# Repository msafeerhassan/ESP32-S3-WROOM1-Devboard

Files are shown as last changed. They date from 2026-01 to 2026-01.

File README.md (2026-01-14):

# ESP32-S3-WROOM1-Devboard
A Custom ESP32-S3-WROOM1 N16R8 Development Board completely designed by me.

This project features raw ESP32-S3-WROOM1 N16R8 Chip to convert it into a professional development board. Several resistors are used along with capacitors for perfect circuit current flowing. 3 RGB colored LEDS are also placed on the PCB alongwith two Switch Push Buttons. A cool logo is placed on bottom right while text with each Pin is mentioned for ease of use in real life.

## Schematic Diagram:



## PCB:





### Made by Safeer Hassan

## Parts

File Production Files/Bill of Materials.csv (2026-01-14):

Component | Quantity
10uF 50V Capacitors | 3
22uF 50V Capacitors | 2
100nF Capacitors | 3
LD1117S33TR SOT223 | 1
S3-WROOM-1-N16R8 | 1
5.1K Ohms Resistors | 5
PinHeader_1x20_P2.00mm_Vertical | 2
USB-C Receptacle_HCTL_HC-TYPE-C-16P-01A | 1
RED LED | 1
BLUE LED | 1
GREEN LED | 1
SW_PUSH Button | 2
Note: (PCBA to be ordered, so no product prices/links)

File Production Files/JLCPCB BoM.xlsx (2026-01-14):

Comment | Designator | Footprint
10uf | C1,C3 | 1206
22uf | C4 | 1206
100nf | C2,C5 | 603
RED | D1 | 805
GREEN | D2 | 805
BLUE | D3 | 805
USB_C_Receptacle_USB2.0_16P | J1 | USB_C_Receptacle_HCTL_HC-TYPE-C-16P-01A
Conn_01x20_Pin | J2,J3 | PinHeader_1x20_P2.00mm_Vertical
5.1k | R1,R2,R3,R4,R5 | 603
SW_Push | SW1,SW2 | SW_SPST_B3S-1000
ESP32-S3-WROOM-1 | U1 | ESP32-S3-WROOM-1
LD1117S33TR_SOT223 | U2 | SOT-223-3_TabPin2

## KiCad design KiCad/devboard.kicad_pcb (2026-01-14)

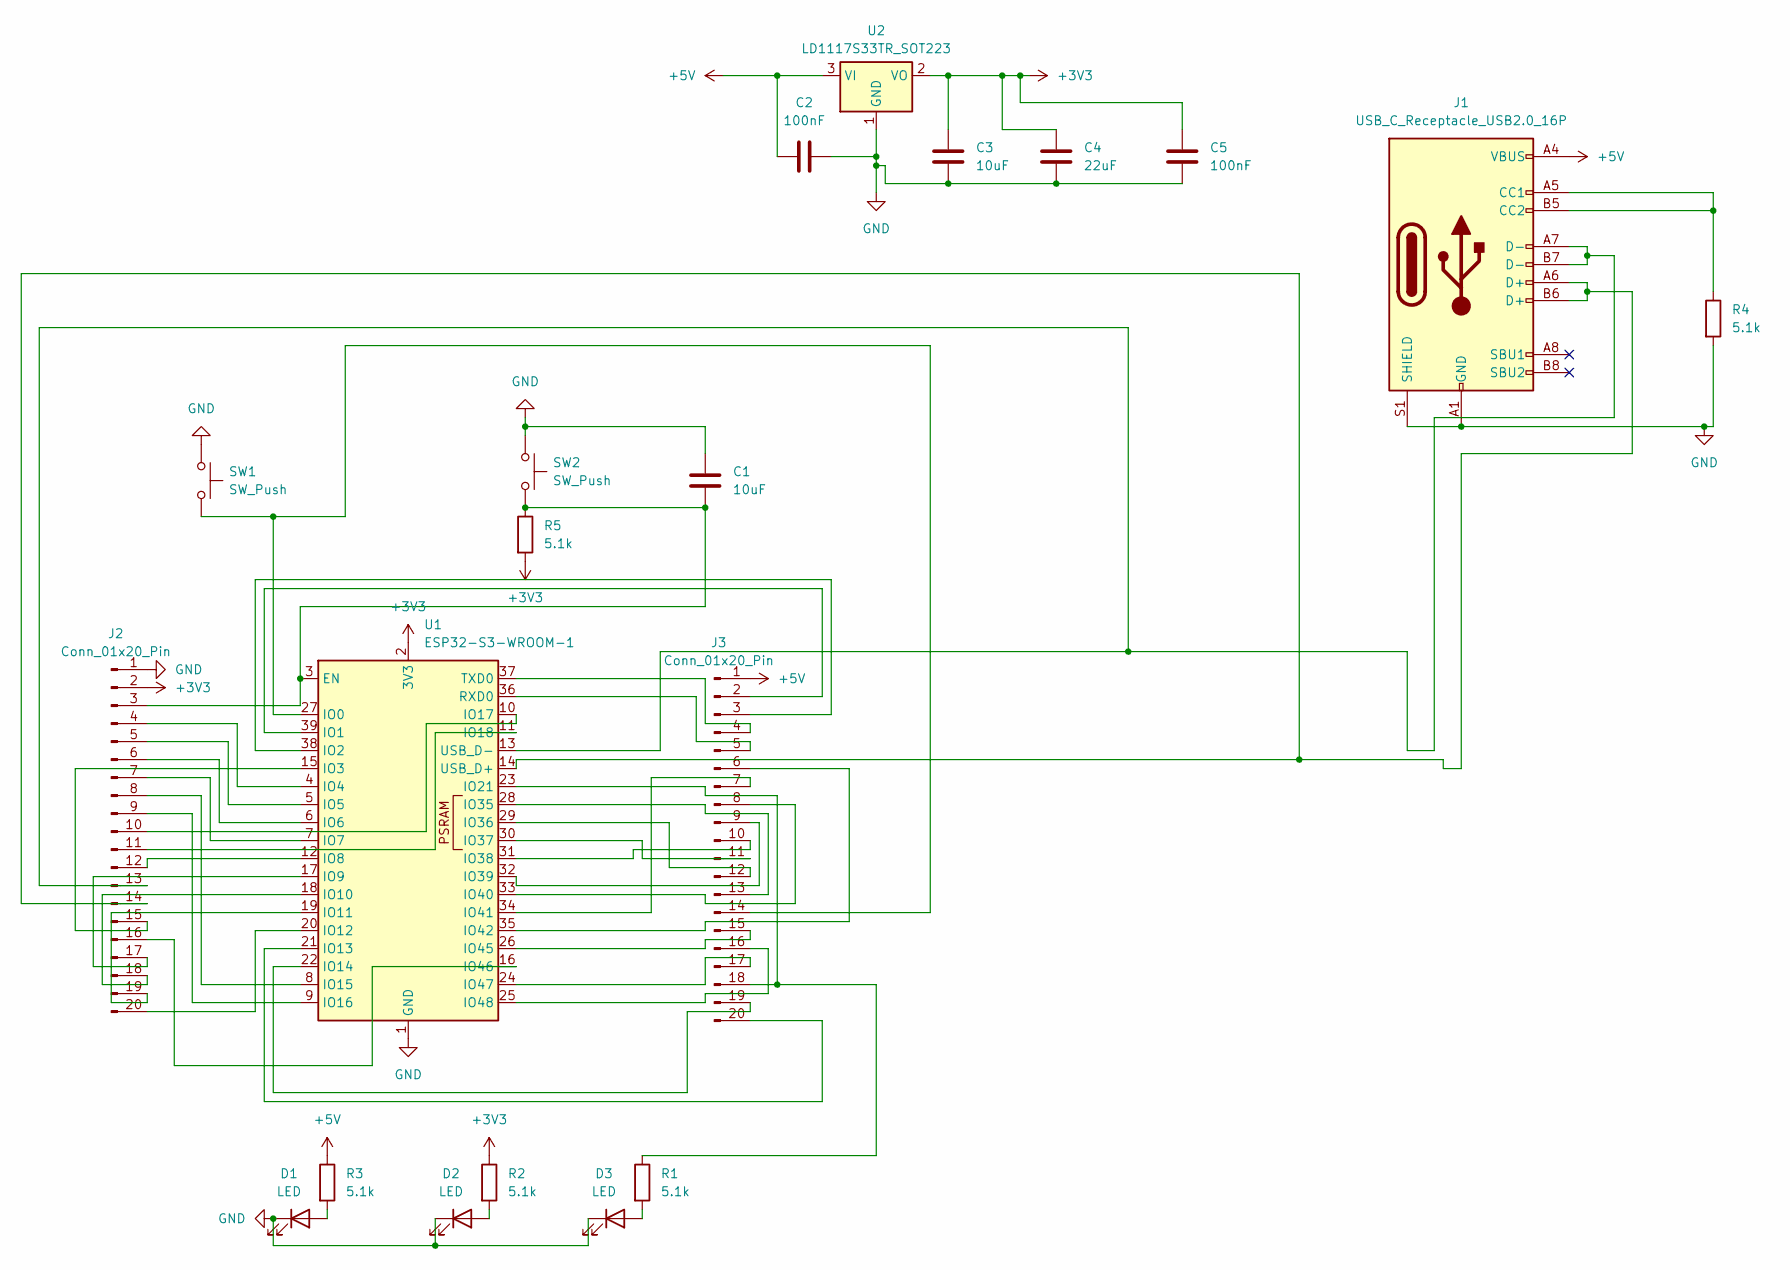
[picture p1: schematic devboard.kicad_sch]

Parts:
C1, C3: 10uF; C_1206_3216Metric_Pad1.33x1.80mm_HandSolder
C2, C5: 100nF; C_0603_1608Metric_Pad1.08x0.95mm_HandSolder
C4: 22uF; C_1206_3216Metric_Pad1.33x1.80mm_HandSolder
D1, D2, D3: LED; LED_0805_2012Metric_Pad1.15x1.40mm_HandSolder
J1: USB_C_Receptacle_USB2.0_16P; USB_C_Receptacle_HCTL_HC-TYPE-C-16P-01A
J2, J3: Conn_01x20_Pin; PinHeader_1x20_P2.00mm_Vertical
R1, R2, R3, R4, R5: 5.1k; R_0603_1608Metric_Pad0.98x0.95mm_HandSolder
SW1, SW2: SW_Push; SW_SPST_B3S-1000
U1: ESP32-S3-WROOM-1
U2: LD1117S33TR_SOT223; SOT-223-3_TabPin2

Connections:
+3V3: C3.1, C4.1, C5.1, J2.2, R2.1, R5.2, U1.2 (3V3), U2.2 (VO)
+5V: C2.1, J1.A4 (VBUS), J1.A9 (VBUS), J1.B4 (VBUS), J1.B9 (VBUS), J3.1, R3.1, U2.3 (VI)
GND: C1.1, C2.2, C3.2, C4.2, C5.2, D1.1 (K), D2.1 (K), D3.1 (K), J1.A1 (GND), J1.A12 (GND), J1.B1 (GND), J1.B12 (GND), J1.S1 (SHIELD), J2.1, R4.2, SW1.1, SW2.1, U1.1 (GND), U1.40 (GND), U1.41 (GND), U2.1 (GND)
unnamed: D1.2 (A), R3.2
unnamed: D2.2 (A), R2.2
unnamed: D3.2 (A), R1.2
unnamed: J1.A5 (CC1), J1.B5 (CC2), R4.1
unnamed: C1.2, J2.3, R5.1, SW2.2, U1.3 (EN)
unnamed: J2.4, U1.4 (IO4)
unnamed: J2.5, U1.5 (IO5)
unnamed: J2.6, U1.6 (IO6)
unnamed: J2.7, U1.7 (IO7)
unnamed: J2.8, U1.8 (IO15)
unnamed: J2.9, U1.9 (IO16)
unnamed: J2.10, U1.10 (IO17)
unnamed: J2.11, U1.11 (IO18)
unnamed: J2.12, U1.12 (IO8)
unnamed: J1.A7 (D-), J1.B7 (D-), J2.13, U1.13 (USB_D-)
unnamed: J1.A6 (D+), J1.B6 (D+), J2.14, U1.14 (USB_D+)
unnamed: J2.15, U1.15 (IO3)
unnamed: J2.16, U1.16 (IO46)
unnamed: J2.17, U1.17 (IO9)
unnamed: J2.18, U1.18 (IO10)
unnamed: J2.19, U1.19 (IO11)
unnamed: J2.20, U1.20 (IO12)
unnamed: J3.2, U1.39 (IO1)
unnamed: J3.3, U1.38 (IO2)
unnamed: J3.4, U1.37 (TXD0)
unnamed: J3.5, U1.36 (RXD0)
unnamed: J3.6, U1.35 (IO42)
unnamed: J3.7, U1.34 (IO41)
unnamed: J3.8, U1.33 (IO40)
unnamed: J3.9, U1.32 (IO39)
unnamed: J3.10, U1.31 (IO38)
unnamed: J3.11, U1.30 (IO37)
unnamed: J3.12, U1.29 (IO36)
unnamed: J3.13, U1.28 (IO35)
unnamed: J3.14, SW1.2, U1.27 (IO0)
unnamed: J3.15, U1.26 (IO45)
unnamed: J3.16, U1.25 (IO48)
unnamed: J3.17, U1.24 (IO47)
unnamed: J3.18, R1.1, U1.23 (IO21)
unnamed: J3.19, U1.22 (IO14)
unnamed: J3.20, U1.21 (IO13)

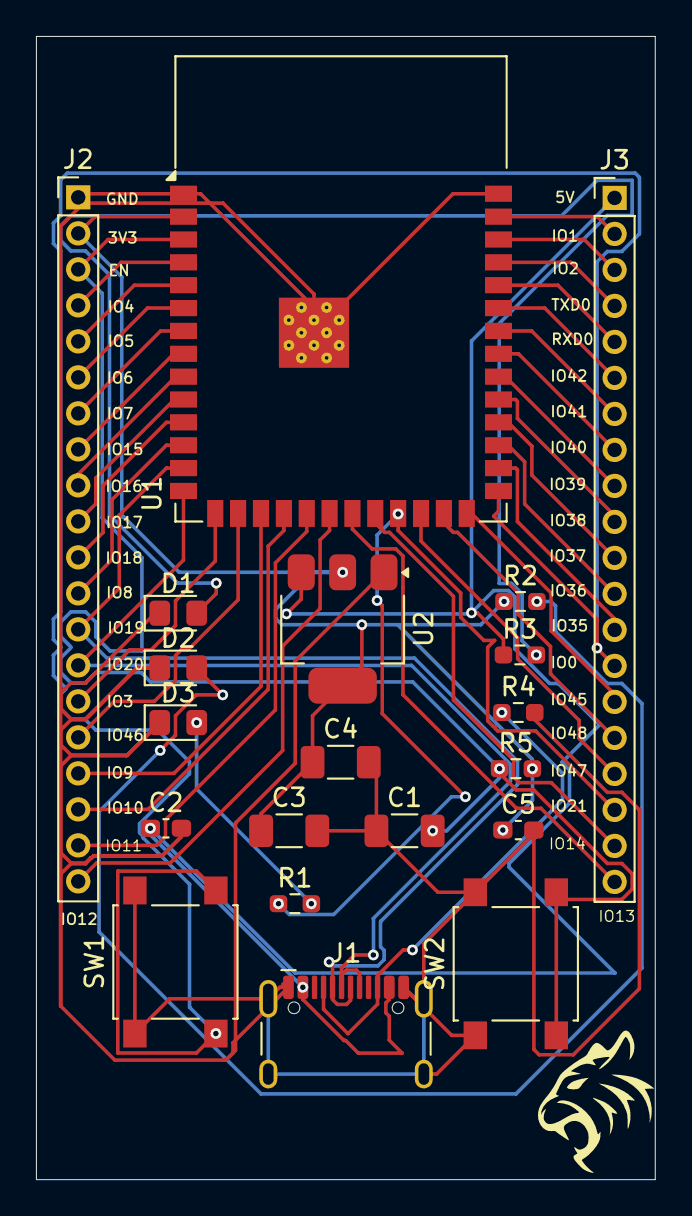
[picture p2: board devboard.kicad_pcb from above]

Board: 2 copper layers, 34.4 x 63.5 mm, 20 parts (0 on the bottom side), 44 nets.

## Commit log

2026-01-14 added KiCad files
    [devboard.kicad_pcb, devboard.kicad_sch]
2026-01-14 uploaded production files
    [Bill of Materials.csv, JLCPCB BoM.xlsx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]
2026-01-14 Enhance README with detailed project information
    Expanded project description and added schematic and PCB images.
